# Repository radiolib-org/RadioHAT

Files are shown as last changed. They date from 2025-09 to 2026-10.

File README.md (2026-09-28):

# RadioHAT
Raspberry Pi PCIe HAT for radio modules

This HAT is an all-in-one radio modules development platform with the following features. 

* **Built-in logic analyzer** - All pins routed to the transceivers (SPI and various GPIO signals) are also routed to additional Raspberry Pi GPIO pins, to allow the RPi to monitor and record the state of communication pins. See the [pinalyzer repository](https://github.com/radiolib-org/pinalyzer) for details.
* **Adjustable linear voltage regulator** - To supply power-intensive transceivers, there is a dedicated LDO regulator with adjustable output. The output voltage is adjustable between 2.9 and 3.6 V.
* **Power consumption measurement** - There is a built-in INA219 current monitor which allows to measure the power consumption of the transceiver. See the [dc-powermon repository](https://github.com/radiolib-org/dc-powermon) for details.

While these features are useful, they are entirely optional. Without them, the HAT is a simple adapter board for mini-PCIe cards (half-size or full-size) and can be left with most of the components unpopulated, except for the RPi pin header, PCIe connector and the card latch.

## RadioHAT
RadioHAT

## Card for modules from Dorji
RadioHAT Dorji card

## Card for modules from GNice-RF
RadioHAT GNice-RF card

## Card for modules from Ebyte
RadioHAT Ebyte card

## Card for Wio-E5
RadioHAT Wio-E5 card

## Mini PCIe connector pinout
Different vendors (RAK Wireless, Waveshare, SeeedStudio and others) offer radio modules in the mini-PCIe card form factor. However, there seems to be no consensus on any specific pinout. Naturally, RadioLib defines its own version to add to the confusion. However, we try to adhere to the standard Mini PCIe 2.0 pinout in the following ways:

* Mini PCIe 2.0 SMB pins are used for I2C
* Mini PCIe 2.0 USB pins are used for USB
* IRQs, resets and various GPIOs are connected to Mini PCIe 2.0 digital signals
* 3.3V voltage pins are used for most modules, though sometimes 5V is optionally used 

The complete pinout of the connector (and therefore the PCIe cards) is shown below.

| Pin | Signal | Signal | Pin |
| --- | --- | --- | --- |
| 1 | GPIO0 | 3V3 | 2 |
| 3 | IRQ0 | GND | 4 |
| 5 | IRQ1 | 5V | 6 |
| 7 | GPIO1 | NC | 8 |
| 9 | GND | NC | 10  |
|  11 | RST0 | NC | 12  |
|  13 | RST1 | NC | 14  |
|  15 | GND | NC | 16  |
|  17 | NC | GND | 18  |
|  19 | NC | NSS1 | 20  |
|  21 | GND | NC | 22  |
|  23 | NC | 3V3 | 24  |
|  25 | NC | GND | 26  |
|  27 | GND | 5V | 28  |
|  29 | GND | I2C_SCL  | 30  |
|  31 | PPS | I2C_SDA  | 32  |
|  33 | NC | GND | 34  |
|  35 | GND | USB_D- | 36  |
|  37 | GND | USB_D+ | 38  |
|  39 | 3V3 | GND | 40  |
|  41 | 3V3 | LED0 | 42  |
|  43 | GND | LED1 | 44  |
|  45 | SPI_SCK  | LED2 | 46  |
|  47 | SPI_MISO | 5V | 48  |
|  49 | SPI_MOSI | GND | 50  |
|  51 | NSS0 | 3V3 | 52  |

## Raspberry Pi pinout

The shield routes the Mini PCIe connector signals to the following Raspberry Pi GPIO header pins. The pins with prefix `SNS_` are connected to the digital signals through a series resistor and GPIO, allowing to use the RPi as a makeshift logic analyzer.

| Pin | Signal | Signal | Pin |
| --- | --- | --- | --- |
| 1 | 3V3 | 5V | 2 |
| 3 | I2C_SCL | 5V | 4 |
| 5 | I2C_SDA | GND | 6 |
| 7 | SNS_NSS0  | SNS_SDA | 8 |
| 9 | GND | SNS_SCL | 10  |
|  11 | SNS_SCK | RST0 | 12  |
|  13 | SNS_MISO  | GND | 14  |
|  15 | SNS_MOSI  | GPIO1 | 16  |
|  17 | 3V3 | IRQ1 | 18  |
|  19 | SPI_MOSI  | GND | 20  |
|  21 | SPI_MISO  | RST1 | 22  |
|  23 | SPI_SCK | NSS0 | 24  |
|  25 | GND | NSS1 | 26  |
|  27 | NC | NC | 28  |
|  29 | SNS_IRQ0  | GND | 30  |
|  31 | SNS_RST0  | SNS_GPIO0 | 32  |
|  33 | SNS_NSS1  | GND | 34  |
|  35 | SNS_IRQ1  | IRQ0 | 36  |
|  37 | SNS_GPIO1 | GPIO0 | 38  |
|  39 | GND | SNS_RST1  | 40  |

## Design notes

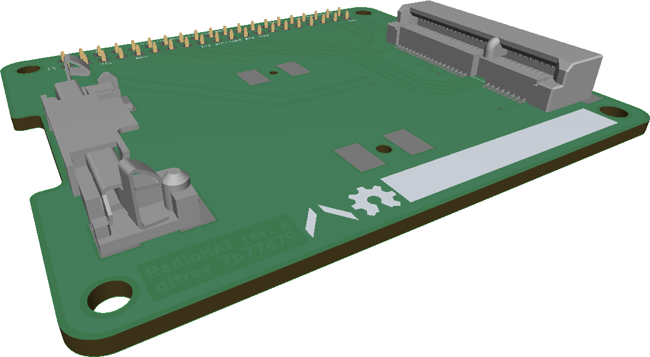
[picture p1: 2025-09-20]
doc/RadioHAT-3D_top.png

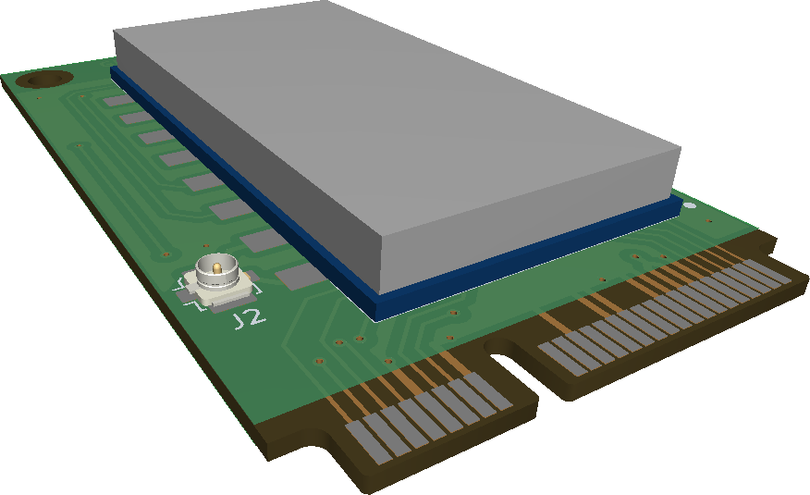
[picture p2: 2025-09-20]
doc/RadioHAT_Card_GNiceRF-3D_top.png

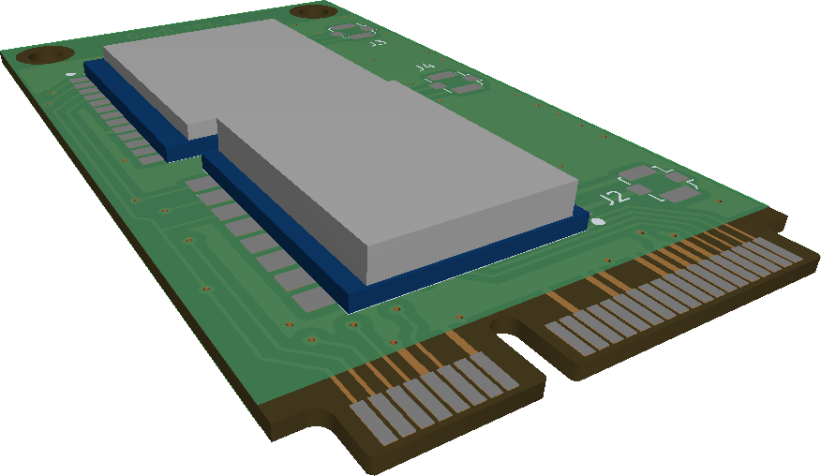
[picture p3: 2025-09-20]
doc/RadioHAT_Card_Dorji-3D_top.png

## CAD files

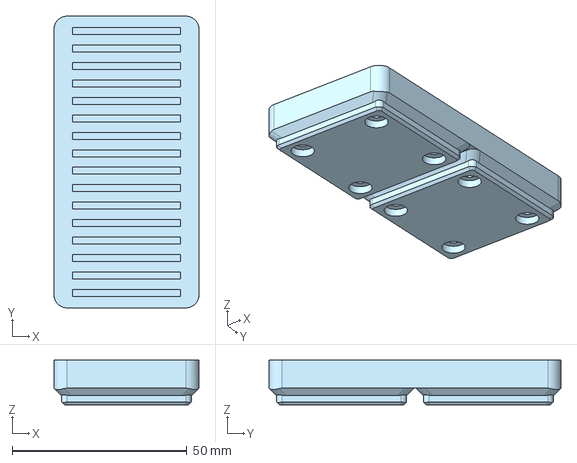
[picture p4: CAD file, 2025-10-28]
stp/gridfinity_card_holder.step
41.5 x 83.5 x 12.8 mm

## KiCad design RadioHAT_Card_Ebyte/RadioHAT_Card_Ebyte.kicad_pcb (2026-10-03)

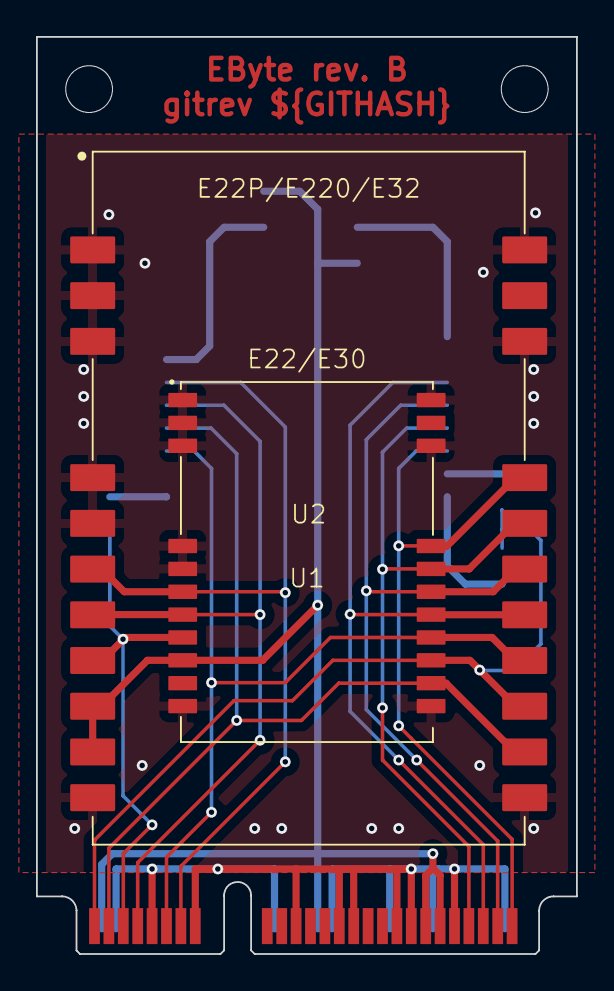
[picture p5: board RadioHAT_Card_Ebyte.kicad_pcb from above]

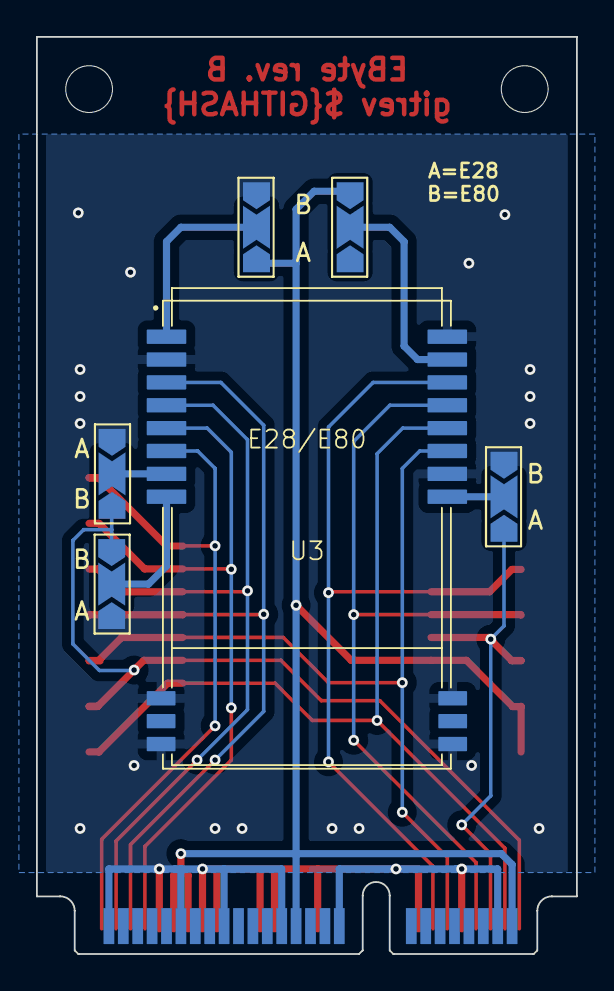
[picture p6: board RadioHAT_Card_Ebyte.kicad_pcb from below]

Board: 2 copper layers, 30.0 x 50.9 mm, 9 parts (6 on the bottom side), 17 nets.

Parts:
J1: Mini_PCIe_Full
JP1, JP2, JP3, JP4, JP5: SolderJumper_3_Open; SolderJumper-3_P2.0mm_Open_TrianglePad1.0x1.5mm_NumberLabels
U1: E22_Small
U2: E22_Large
U3: E28_E80

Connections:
+3V3: J1.2 (3V3), J1.24 (3V3), J1.39 (3V3), J1.41 (3V3), JP1.3 (B), JP2.1 (A), U1.9 (VCC), U2.9 (VCC), U2.10 (VCC)
GND: J1.4 (GND), J1.9 (GND), J1.15 (GND), J1.18 (GND), J1.21 (GND), J1.26 (GND), J1.27 (GND), J1.29 (GND), J1.34 (GND), J1.35 (GND), J1.37 (GND), J1.40 (GND), J1.43 (GND), J1.50 (GND), JP2.3 (B), JP3.3 (B), JP4.3 (B), JP5.1 (A), U1.1 (GND), U1.2 (GND), U1.3 (GND), U1.4 (GND), U1.5 (GND), U1.11 (GND), U1.12 (GND), U1.20 (GND_ANT), U1.22 (GND_ANT), U2.1 (GND), U2.2 (GND), U2.3 (GND), U2.4 (GND), U2.5 (GND), U2.11 (GND), U2.12 (GND), U2.20 (GND_ANT), U2.22 (GND_ANT), U3.2 (GND), U3.11 (GND_ANT), U3.13 (GND_ANT), U3.14 (GND_ANT), U3.16 (GND_ANT), U3.20 (GND), U3.26 (GND)
GPIO0: J1.1 (GPIO0), JP3.1 (A), JP5.3 (B), U1.14 (BUSY), U2.14 (BUSY)
GPIO1: J1.7 (GPIO1), U1.7 (TXEN), U2.7 (TXEN), U3.23 (DIO8/DIO1)
IRQ0: J1.3 (IRQ0), U1.13 (DIO1), U2.13 (DIO1), U3.22 (DIO9/BUSY)
IRQ1: J1.5 (IRQ1), JP4.1 (A), U1.8 (DIO2), U2.8 (DIO2)
MISO: J1.47 (SPI_MISO), U1.16 (MISO), U2.16 (MISO), U3.3 (MISO)
MOSI: J1.49 (SPI_MOSI), U1.17 (MOSI), U2.17 (MOSI), U3.4 (MOSI)
NSS: J1.51 (NSS0), U1.19 (NSS), U2.19 (NSS), U3.6 (NSS)
unnamed: JP1.2 (C), U3.25 (VCC/DIO3)
unnamed: JP2.2 (C), U3.1 (GND/VCC)
unnamed: JP3.2 (C), U3.8 (GND/RX_EN)
unnamed: JP4.2 (C), U3.19 (GND/TX_EN)
unnamed: JP5.2 (C), U3.7 (BUSY/GND)
RST0: J1.11 (RST0), U1.15 (NRST), U2.15 (NRST), U3.21 (NRST)
RST1: J1.13 (RST1), U1.6 (RXEN), U2.6 (RXEN), U3.24 (DIO7/DIO2)
SCK: J1.45 (SPI_SCK), U1.18 (SCK), U2.18 (SCK), U3.5 (SCK)

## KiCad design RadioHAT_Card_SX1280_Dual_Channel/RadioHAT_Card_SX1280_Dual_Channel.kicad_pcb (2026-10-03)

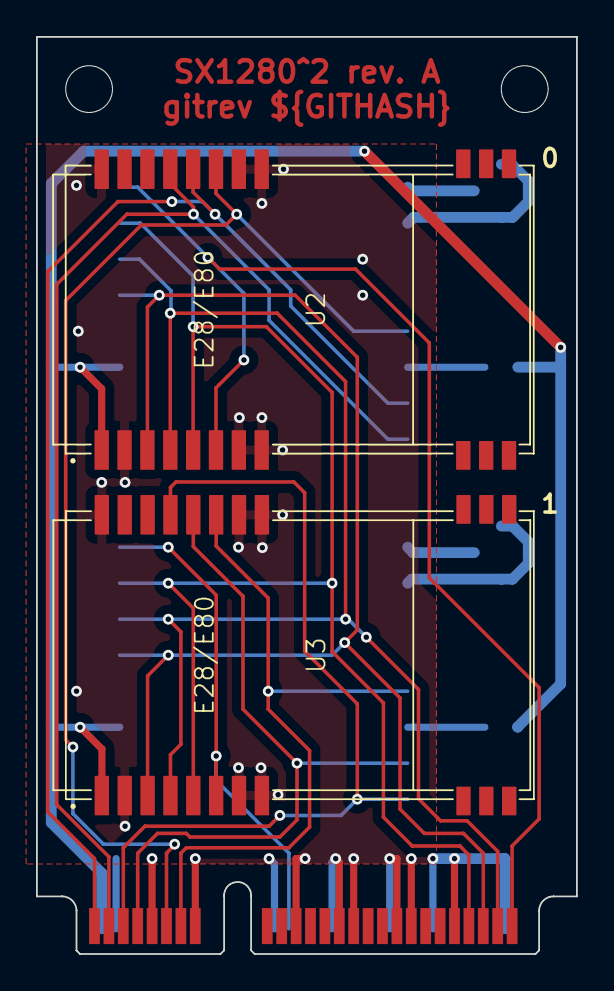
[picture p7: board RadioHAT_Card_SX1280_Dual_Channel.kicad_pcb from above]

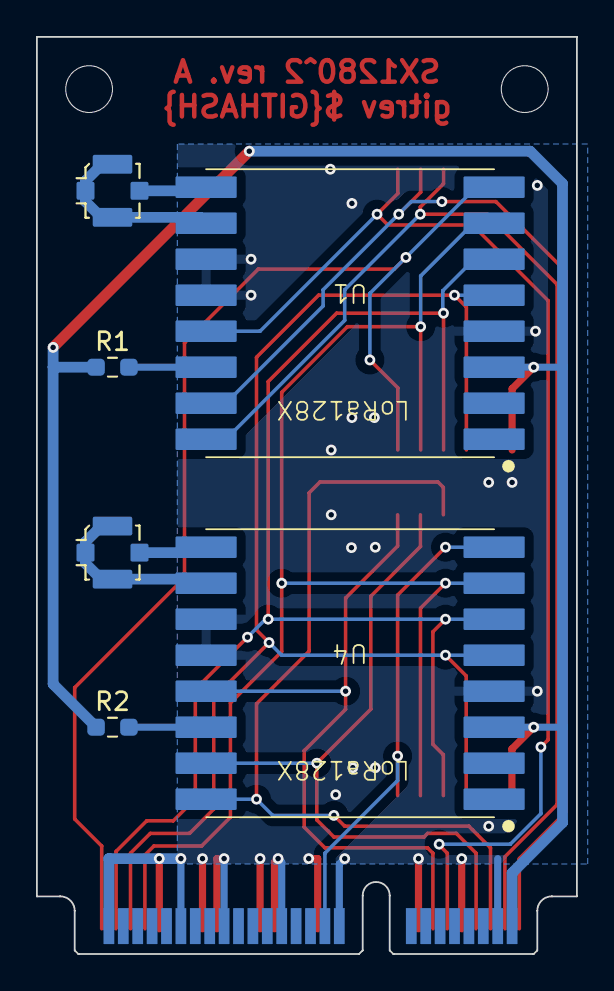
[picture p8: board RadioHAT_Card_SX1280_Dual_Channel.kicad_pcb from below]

Board: 2 copper layers, 30.0 x 51.0 mm, 9 parts (6 on the bottom side), 19 nets.

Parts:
J1: Mini_PCIe_Full
J2, J3: Conn_Coaxial; U.FL_Molex_MCRF_73412-0110_Vertical
R1, R2: 1k; R_0603_1608Metric_Pad0.98x0.95mm_HandSolder
U1, U4: LoRa128X
U2, U3: E28_E80

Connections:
+3V3: J1.2 (3V3), R1.1, R2.1, U1.3 (VCC), U2.1 (GND/VCC), U3.1 (GND/VCC), U4.3 (VCC)
GND: J1.4 (GND), J1.9 (GND), J1.15 (GND), J1.18 (GND), J1.21 (GND), J1.26 (GND), J1.27 (GND), J1.29 (GND), J1.34 (GND), J1.35 (GND), J1.37 (GND), J1.40 (GND), J1.43 (GND), J1.50 (GND), U1.4 (GND), U1.11 (GND), U1.12 (GND), U2.2 (GND), U2.7 (BUSY/GND), U2.8 (GND/RX_EN), U2.19 (GND/TX_EN), U2.20 (GND), U2.26 (GND), U3.2 (GND), U3.7 (BUSY/GND), U3.8 (GND/RX_EN), U3.19 (GND/TX_EN), U3.20 (GND), U3.26 (GND), U4.4 (GND), U4.11 (GND), U4.12 (GND)
GPIO0: J1.1 (GPIO0), U1.15 (BUSY), U2.22 (DIO9/BUSY)
GPIO1: J1.7 (GPIO1), U3.22 (DIO9/BUSY), U4.15 (BUSY)
IRQ0: J1.3 (IRQ0), U1.16 (DIO1), U2.23 (DIO8/DIO1)
IRQ1: J1.5 (IRQ1), U3.23 (DIO8/DIO1), U4.16 (DIO1)
MISO: J1.47 (SPI_MISO), U1.5 (MISO), U2.3 (MISO), U3.3 (MISO), U4.5 (MISO)
MOSI: J1.49 (SPI_MOSI), U1.6 (MOSI), U2.4 (MOSI), U3.4 (MOSI), U4.6 (MOSI)
NSS0: J1.51 (NSS0), U1.8 (NSS), U2.6 (NSS)
NSS1: J1.20 (NSS1), U3.6 (NSS), U4.8 (NSS)
unnamed: J2.2 (Ext), U1.10 (GND_ANT)
unnamed: J2.1 (In), U1.9 (ANT)
unnamed: J3.2 (Ext), U4.10 (GND_ANT)
unnamed: J3.1 (In), U4.9 (ANT)
unnamed: R1.2, U1.14 (TCXOEN)
unnamed: R2.2, U4.14 (TCXOEN)
RST0: J1.11 (RST0), U1.13 (NRESET), U2.21 (NRST)
RST1: J1.13 (RST1), U3.21 (NRST), U4.13 (NRESET)
SCK: J1.45 (SPI_SCK), U1.7 (SCK), U2.5 (SCK), U3.5 (SCK), U4.7 (SCK)

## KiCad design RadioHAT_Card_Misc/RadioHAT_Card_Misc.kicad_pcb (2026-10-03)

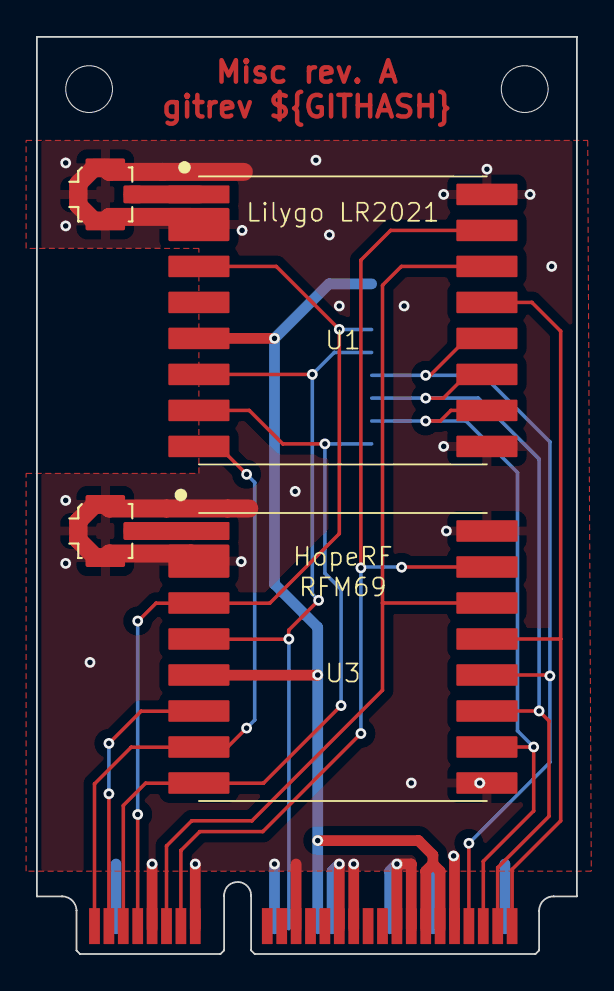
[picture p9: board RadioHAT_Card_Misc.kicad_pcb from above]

Board: 2 copper layers, 30.0 x 51.0 mm, 6 parts (1 on the bottom side), 15 nets.

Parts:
J1: Mini_PCIe_Full
J2, J3: Conn_Coaxial; U.FL_Molex_MCRF_73412-0110_Vertical
U1: Lilygo_LR2021
U2: nRF24
U3: RFM69

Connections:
+3V3: J1.24 (3V3), J1.39 (3V3), J1.41 (3V3), U1.5 (VCC), U2.1 (+3V3), U3.5 (VCC)
GND: J1.4 (GND), J1.9 (GND), J1.15 (GND), J1.18 (GND), J1.21 (GND), J1.26 (GND), J1.27 (GND), J1.29 (GND), J1.34 (GND), J1.35 (GND), J1.37 (GND), J1.40 (GND), J1.43 (GND), J1.50 (GND), J2.2 (Ext), J3.2 (Ext), U1.2 (GND_ANT), U1.9 (GND), U1.16 (GND), U2.2 (GND), U3.2 (GND), U3.9 (GND), U3.16 (GND)
GPIO0: J1.1 (GPIO0), U1.8 (BUSY), U3.7 (DIO1)
GPIO1: J1.7 (GPIO1), U1.3 (DIO8), U2.3 (CE), U3.3 (DIO3)
IRQ0: J1.3 (IRQ0), U3.6 (DIO0)
IRQ1: J1.5 (IRQ1), U1.7 (DIO11), U2.8 (IRQ), U3.8 (DIO2)
MISO: J1.47 (SPI_MISO), U1.10 (MISO), U2.7 (MISO), U3.10 (MISO)
MOSI: J1.49 (SPI_MOSI), U1.11 (MOSI), U2.6 (MOSI), U3.11 (MOSI)
NSS0: J1.51 (NSS0), U1.13 (NSS), U3.13 (NSS)
NSS1: J1.20 (NSS1), U1.6 (DIO10), U2.4 (CSN), U3.4 (DIO4)
unnamed: J2.1 (In), U1.1 (ANT)
unnamed: J3.1 (In), U3.1 (ANT)
RST0: J1.11 (RST0), U1.14 (NRESET), U3.14 (RST)
RST1: J1.13 (RST1), U1.15 (DIO9), U3.15 (DIO5)
SCK: J1.45 (SPI_SCK), U1.12 (SCK), U2.5 (SCK), U3.12 (SCK)

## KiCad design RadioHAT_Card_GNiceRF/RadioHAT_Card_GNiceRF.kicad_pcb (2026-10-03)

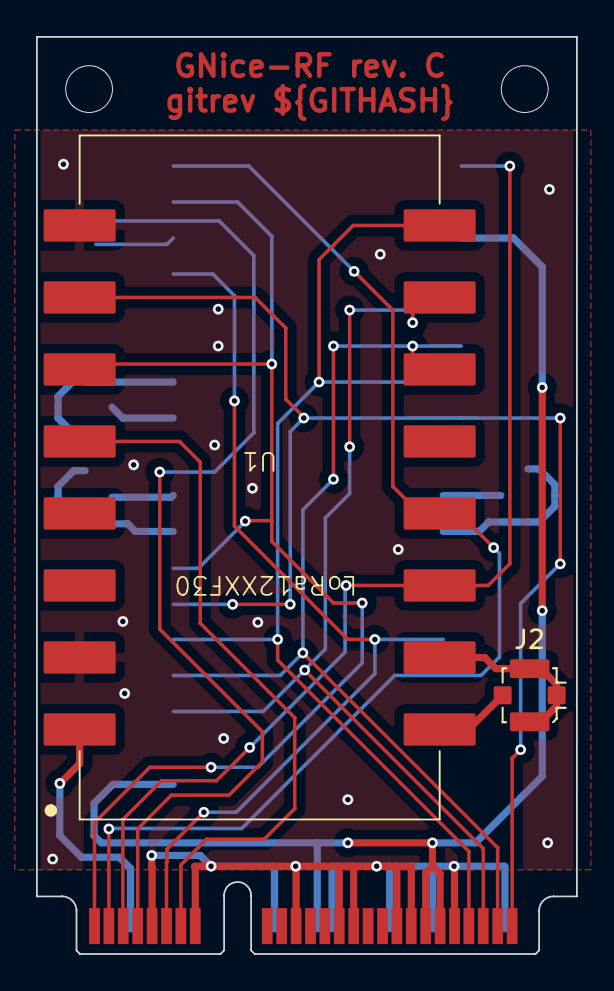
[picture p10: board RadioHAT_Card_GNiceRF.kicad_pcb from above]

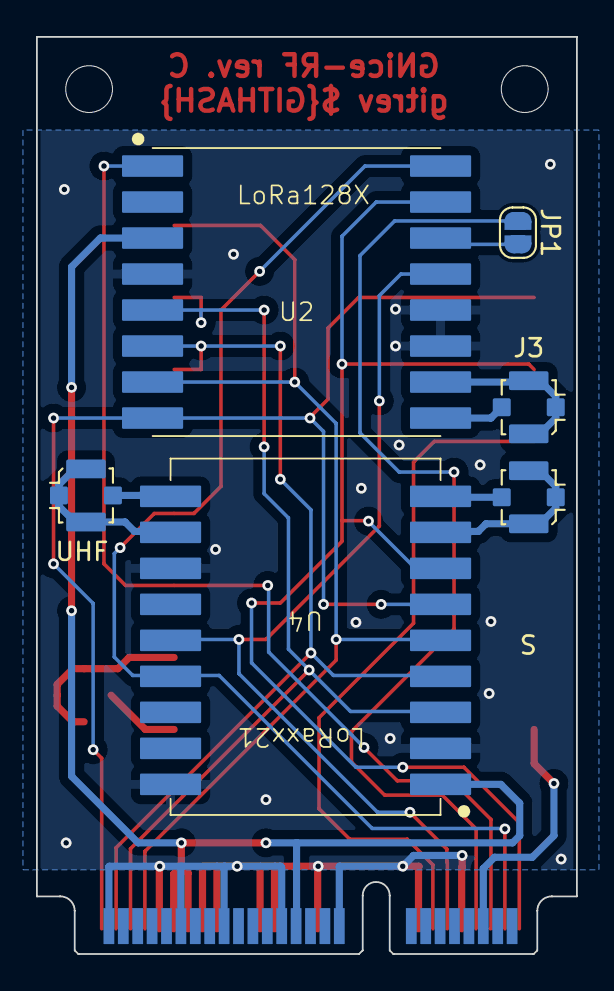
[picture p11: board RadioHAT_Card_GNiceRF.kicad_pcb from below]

Board: 2 copper layers, 30.0 x 51.0 mm, 9 parts (6 on the bottom side), 22 nets.

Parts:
J1: Mini_PCIe_Full
J2, J3, J4, J5: Conn_Coaxial; U.FL_Molex_MCRF_73412-0110_Vertical
JP1: SolderJumper_2_Open; SolderJumper-2_P1.3mm_Open_RoundedPad1.0x1.5mm
U1: LoRa12XXF30
U2: LoRa128X
U4: LoRaxx21

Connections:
+3V3: J1.24 (3V3), J1.39 (3V3), J1.41 (3V3), U2.3 (VCC), U4.1 (VCC)
+5V: J1.6 (5V), U1.1 (VCC)
GND: J1.9 (GND), J1.15 (GND), J1.18 (GND), J1.21 (GND), J1.26 (GND), J1.27 (GND), J1.29 (GND), J1.34 (GND), J1.35 (GND), J1.37 (GND), J1.40 (GND), J1.43 (GND), J1.50 (GND), U1.2 (GND), U1.8 (GND), U2.4 (GND), U2.11 (GND), U2.12 (GND), U4.2 (GND), U4.12 (GND), U4.18 (GND)
GPIO0: J1.1 (GPIO0), U1.6 (DIO0(BUSY)), U2.15 (BUSY), U4.7 (BUSY)
GPIO1: J1.7 (GPIO1), JP1.1 (A)
IRQ0: J1.3 (IRQ0), U1.13 (DIO1), U2.16 (DIO1), U4.15 (DIO9)
IRQ1: J1.5 (IRQ1), U1.14 (DIO4(DIO2)), U2.1 (DIO2)
MISO: J1.47 (SPI_MISO), U1.10 (MISO), U2.5 (MISO), U4.3 (MISO)
MOSI: J1.49 (SPI_MOSI), U1.11 (MOSI), U2.6 (MOSI), U4.4 (MOSI)
NSS: J1.51 (NSS0), U1.7 (NSS), U2.8 (NSS), U4.6 (NSS)
unnamed: J2.2 (Ext), U1.15 (GND_ANT)
unnamed: J2.1 (In), U1.16 (ANT)
unnamed: J3.2 (Ext), U2.10 (GND_ANT)
unnamed: J3.1 (In), U2.9 (ANT)
unnamed: J4.2 (Ext), U4.11 (GND_ANT)
unnamed: J4.1 (In), U4.10 (ANT)
unnamed: J5.2 (Ext), U4.8 (GND_ANT)
unnamed: J5.1 (In), U4.9 (2.4/S_ANT)
unnamed: JP1.2 (B), U2.14 (TCXOEN)
RST0: J1.11 (RST0), U2.13 (NRESET), U4.14 (RST)
RST1: J1.13 (RST1), U1.5 (NRESET)
SCK: J1.45 (SPI_SCK), U1.9 (SCK), U2.7 (SCK), U4.5 (SCK)

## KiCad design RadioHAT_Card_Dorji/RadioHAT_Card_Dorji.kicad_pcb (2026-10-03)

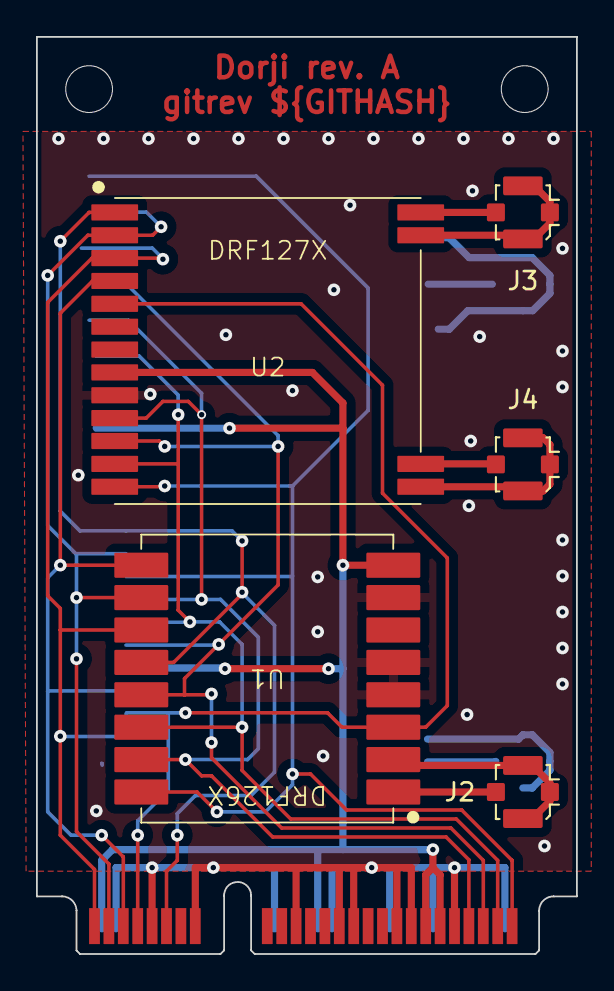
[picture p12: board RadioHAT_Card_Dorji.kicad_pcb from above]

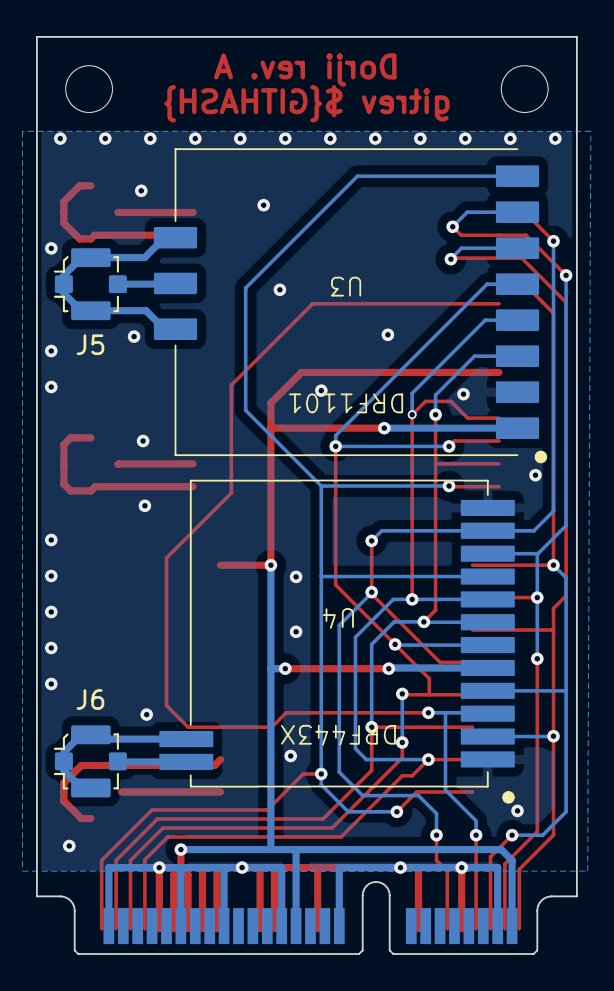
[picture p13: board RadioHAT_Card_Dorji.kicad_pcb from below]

Board: 2 copper layers, 30.0 x 51.0 mm, 10 parts (4 on the bottom side), 21 nets.

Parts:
J1: Mini_PCIe_Full
J2, J3, J4, J5, J6: Conn_Coaxial; U.FL_Molex_MCRF_73412-0110_Vertical
U1: DRF126X
U2: DRF127X
U3: DRF1101
U4: DRF443X

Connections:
+3V3: J1.2 (3V3), J1.24 (3V3), J1.39 (3V3), J1.41 (3V3), U1.8 (VDD), U2.8 (VCC), U3.1 (PWR), U4.5 (VCC)
GND: J1.4 (GND), J1.9 (GND), J1.15 (GND), J1.18 (GND), J1.21 (GND), J1.26 (GND), J1.27 (GND), J1.29 (GND), J1.34 (GND), J1.35 (GND), J1.37 (GND), J1.40 (GND), J1.43 (GND), J1.50 (GND), U1.4 (GND), U1.5 (GND), U1.7 (GND), U2.9 (GND), U3.2 (GND), U4.1 (GND), U4.12 (GND)
GPIO0: J1.1 (GPIO0), U1.11 (BUSY), U2.3 (DIO1), U3.6 (GPIO2), U4.2 (GPIO0)
GPIO1: J1.7 (GPIO1), U1.3 (SW), U2.5 (DIO3), U4.3 (GPIO1)
IRQ0: J1.3 (IRQ0), U1.10 (DIO1), U2.2 (DIO0), U3.7 (GPIO0), U4.10 (nIRQ)
IRQ1: J1.5 (IRQ1), U1.9 (DIO2), U2.4 (DIO2), U4.4 (GPIO2)
MISO: J1.47 (SPI_MISO), U1.13 (MISO), U2.11 (MISO), U3.5 (SDO), U4.6 (SDO)
MOSI: J1.49 (SPI_MOSI), U1.14 (MOSI), U2.12 (MOSI), U3.3 (SDI), U4.7 (SDI)
NSS: J1.51 (NSS0), U1.16 (NSS), U2.13 (NSS), U3.8 (CSN), U4.9 (nSEL)
unnamed: J2.2 (Ext), U1.2 (GND_ANT)
unnamed: J2.1 (In), U1.1 (ANT)
unnamed: J3.2 (Ext), U2.16 (GND_SX1278)
unnamed: J3.1 (In), U2.17 (ANT_SX1278)
unnamed: J4.2 (Ext), U2.14 (GND_SX1272)
unnamed: J4.1 (In), U2.15 (ANT_SX1272)
unnamed: J5.2 (Ext), U3.9 (GND_ANT), U3.11 (GND_ANT)
unnamed: J5.1 (In), U3.10 (ANT)
unnamed: J6.2 (Ext), U4.14 (GND_ANT)
unnamed: J6.1 (In), U4.13 (ANT)
RST0: J1.11 (RST0), U1.12 (RST), U2.1 (RESET), U4.11 (SDN)
SCK: J1.45 (SPI_SCK), U1.15 (SCK), U2.10 (SCK), U3.4 (SCLK), U4.8 (SCLK)

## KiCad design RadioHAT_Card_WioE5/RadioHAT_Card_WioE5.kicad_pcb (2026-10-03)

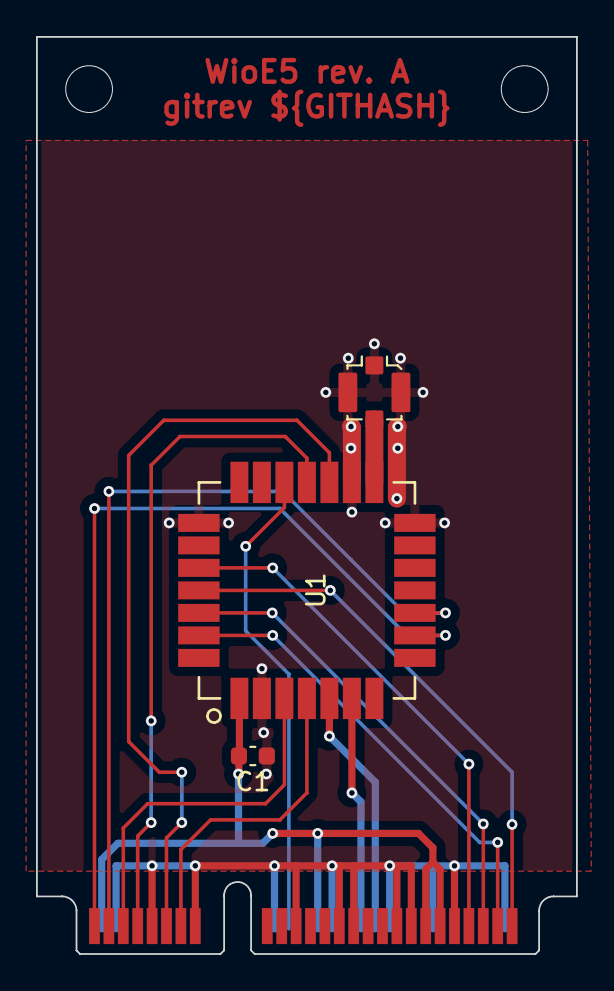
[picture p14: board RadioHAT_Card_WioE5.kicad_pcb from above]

Board: 2 copper layers, 30.0 x 51.0 mm, 4 parts (0 on the bottom side), 16 nets.

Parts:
C1: 100n; C_0603_1608Metric
J1: Mini_PCIe_Full
J2: Conn_Coaxial; U.FL_Molex_MCRF_73412-0110_Vertical
U1: LoRa-E5

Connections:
+3V3: C1.2, J1.2 (3V3), J1.24 (3V3), J1.39 (3V3), J1.41 (3V3), U1.1 (VCC)
GND: C1.1, J1.4 (GND), J1.9 (GND), J1.15 (GND), J1.18 (GND), J1.21 (GND), J1.26 (GND), J1.27 (GND), J1.29 (GND), J1.34 (GND), J1.35 (GND), J1.37 (GND), J1.40 (GND), J1.43 (GND), J1.50 (GND), J2.2 (Ext), U1.2 (GND), U1.14 (GND), U1.16 (GND), U1.22 (GND)
GPIO0: J1.1 (GPIO0), U1.9 (PB7)
GPIO1: J1.7 (GPIO1), U1.18 (PA3)
IRQ0: J1.3 (IRQ0), U1.10 (PB6)
IRQ1: J1.5 (IRQ1), U1.3 (PA13)
MISO: J1.47 (SPI_MISO), U1.26 (PB14)
MOSI: J1.49 (SPI_MOSI), U1.27 (PA10)
NSS0: J1.51 (NSS0), U1.25 (PB9)
NSS1: J1.20 (NSS1), U1.19 (PA2)
unnamed: J2.1 (In), U1.15 (RFIO)
RST0: J1.11 (RST0), U1.17 (RST)
RST1: J1.13 (RST1), U1.4 (PA14)
SCK: J1.45 (SPI_SCK), U1.24 (PB13~)
SCL: J1.32 (I2C_SCL), U1.5 (PB15)
SDA: J1.30 (I2C_SDA), U1.6 (PA15)

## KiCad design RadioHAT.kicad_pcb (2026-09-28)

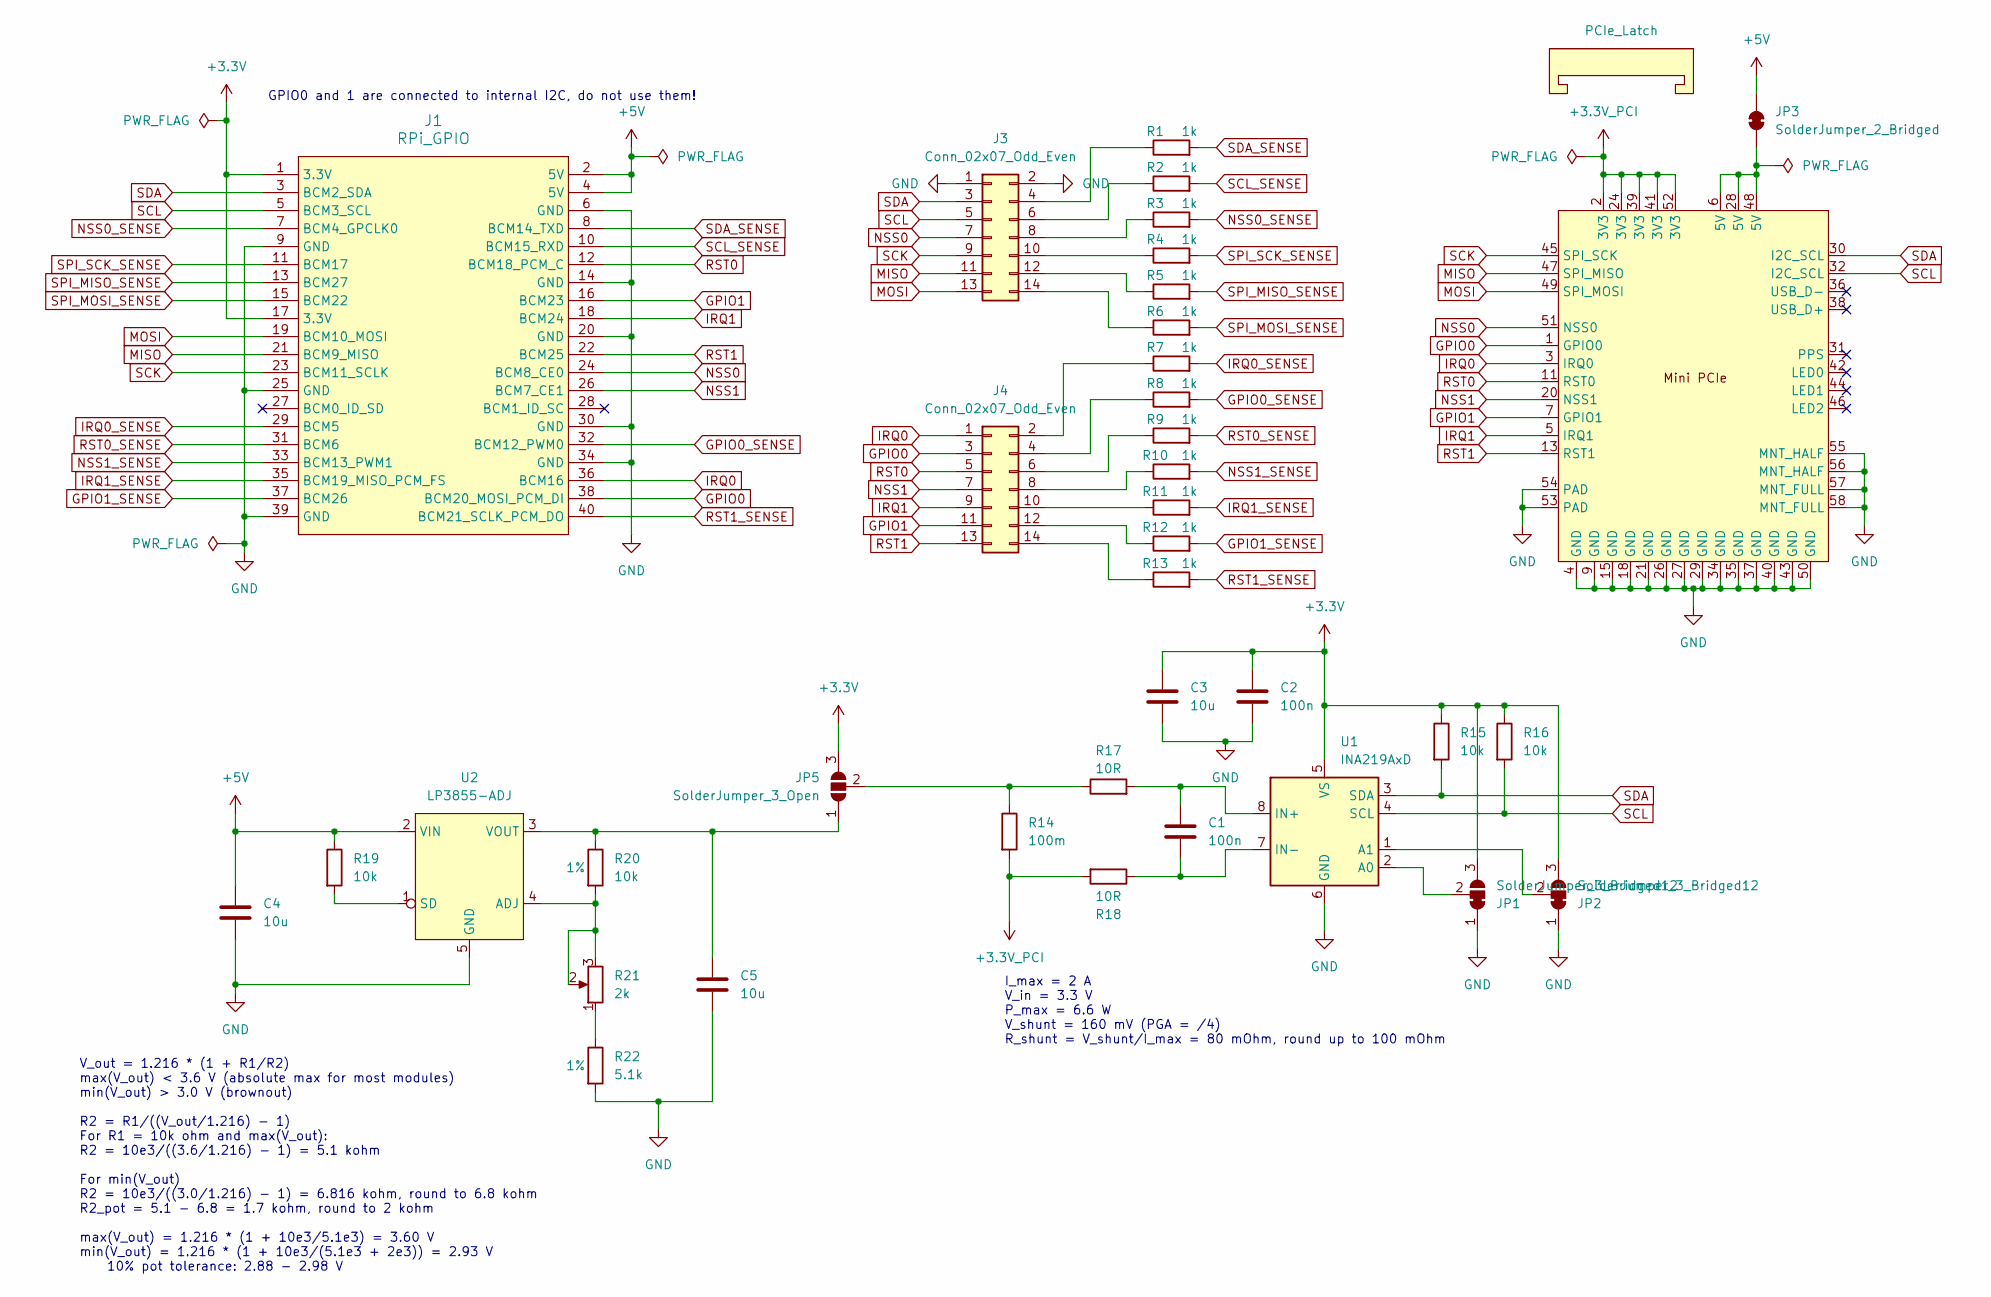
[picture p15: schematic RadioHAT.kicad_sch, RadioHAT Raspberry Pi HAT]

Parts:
C1, C2: 100n; C_0603_1608Metric_Pad1.08x0.95mm_HandSolder; Mouser 963-MAJCU168BB7104KT
C3, C4, C5: 10u; C_0805_2012Metric_Pad1.18x1.45mm_HandSolder; Mouser 581-KAM21AR71A106MU
J1: RPi_GPIO; RPI_Hat_B+; Mouser 200-SSQ12004TD
J2: Mini_PCIe_Latch_Hole; Mouser 571-1775838-2
J3, J4: Conn_02x07_Odd_Even; PinHeader_2x07_P2.54mm_Vertical; Mouser 523-G800LW589018EU
JP1, JP2: SolderJumper_3_Bridged12; SolderJumper-3_P1.3mm_Bridged12_Pad1.0x1.5mm_NumberLabels
JP3: SolderJumper_2_Bridged; SolderJumper-2_P1.3mm_Bridged_Pad1.0x1.5mm
JP5: SolderJumper_3_Open; SolderJumper-3_P1.3mm_Open_Pad1.0x1.5mm_NumberLabels
R1, R2, R3, R4, R5, R6, R7, R8, R9, R10, R11, R12, R13: 1k; R_0603_1608Metric_Pad0.98x0.95mm_HandSolder; Mouser 603-AC0603JR-131KL
R14: 100m; R_2512_6332Metric_Pad1.40x3.35mm_HandSolder_Bypass; Mouser 588-PCS2512DR1000ET
R15, R16, R19: 10k; R_0603_1608Metric_Pad0.98x0.95mm_HandSolder; Mouser 603-AF0603FR-0710KL
R17, R18: 10R; R_0603_1608Metric_Pad0.98x0.95mm_HandSolder; Mouser 71-CRCW060310R0FKEAC
R20: 10k; R_0603_1608Metric_Pad0.98x0.95mm_HandSolder; Tolerance 1%; Mouser 603-AF0603FR-0710KL
R21: 2k; Potentiometer_Bourns_3362P1200LF; Mouser 652-3362P-1-202LF
R22: 5.1k; R_0603_1608Metric_Pad0.98x0.95mm_HandSolder; Tolerance 1%; Mouser 279-CRG0603F5K1
U1: INA219AxD; SOIC-8_3.9x4.9mm_P1.27mm; Mouser 595-INA219AIDR
U2: LP3855-ADJ; SOT150P700X180-5N; Mouser 926-LP3855EMPADJNOPB
X1: PCIe_Latch; Mouser 538-48099-5701

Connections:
+3.3V: C2.1, C3.1, J1.1 (3.3V), J1.17 (3.3V), JP1.3 (B), JP2.3 (B), JP5.3 (B), R15.1, R16.1, U1.5 (VS)
+3.3V_PCI: J2.2 (3V3), J2.24 (3V3), J2.39 (3V3), J2.41 (3V3), J2.52 (3V3), R14.2, R18.2
+5V: C4.1, J1.2 (5V), J1.4 (5V), JP3.2 (B), R19.1, U2.2 (VIN)
GND: C2.2, C3.2, C4.2, C5.2, J1.6 (GND), J1.9 (GND), J1.14 (GND), J1.20 (GND), J1.25 (GND), J1.30 (GND), J1.34 (GND), J1.39 (GND), J2.4 (GND), J2.9 (GND), J2.15 (GND), J2.18 (GND), J2.21 (GND), J2.26 (GND), J2.27 (GND), J2.29 (GND), J2.34 (GND), J2.35 (GND), J2.37 (GND), J2.40 (GND), J2.43 (GND), J2.50 (GND), J2.53 (PAD), J2.54 (PAD), J2.55 (MNT_HALF), J2.56 (MNT_HALF), J2.57 (MNT_FULL), J2.58 (MNT_FULL), J3.1, J3.2, JP1.1 (A), JP2.1 (A), R22.2, U1.6 (GND), U2.5 (GND)
GPIO0: J1.38 (BCM20_MOSI_PCM_DI), J2.1 (GPIO0), J4.3
GPIO0_SENSE: J1.32 (BCM12_PWM0), R8.2
GPIO1: J1.16 (BCM23), J2.7 (GPIO1), J4.11
GPIO1_SENSE: J1.37 (BCM26), R12.2
IRQ0: J1.36 (BCM16), J2.3 (IRQ0), J4.1
IRQ0_SENSE: J1.29 (BCM5), R7.2
IRQ1: J1.18 (BCM24), J2.5 (IRQ1), J4.9
IRQ1_SENSE: J1.35 (BCM19_MISO_PCM_FS), R11.2
MISO: J1.21 (BCM9_MISO), J2.47 (SPI_MISO), J3.11
MOSI: J1.19 (BCM10_MOSI), J2.49 (SPI_MOSI), J3.13
NSS0: J1.24 (BCM8_CE0), J2.51 (NSS0), J3.7
NSS0_SENSE: J1.7 (BCM4_GPCLK0), R3.2
NSS1: J1.26 (BCM7_CE1), J2.20 (NSS1), J4.7
NSS1_SENSE: J1.33 (BCM13_PWM1), R10.2
unnamed: J3.4, R1.1
unnamed: J3.6, R2.1
unnamed: J3.8, R3.1
unnamed: J3.10, R4.1
unnamed: J3.12, R5.1
unnamed: J3.14, R6.1
unnamed: J4.2, R7.1
unnamed: J4.4, R8.1
unnamed: J4.6, R9.1
unnamed: J4.8, R10.1
unnamed: J4.10, R11.1
unnamed: J4.12, R12.1
unnamed: J4.14, R13.1
unnamed: JP1.2 (C), U1.2 (A0)
unnamed: JP2.2 (C), U1.1 (A1)
unnamed: J2.6 (5V), J2.28 (5V), J2.48 (5V), JP3.1 (A)
unnamed: C5.1, JP5.1 (A), R20.1, U2.3 (VOUT)
unnamed: JP5.2 (C), R14.1, R17.1
unnamed: R21.1, R22.1
unnamed: C1.1, R17.2, U1.8 (IN+)
unnamed: C1.2, R18.1, U1.7 (IN-)
unnamed: R20.2, R21.2, R21.3, U2.4 (ADJ)
unnamed: R19.2, U2.1 (SD)
RST0: J1.12 (BCM18_PCM_C), J2.11 (RST0), J4.5
RST0_SENSE: J1.31 (BCM6), R9.2
RST1: J1.22 (BCM25), J2.13 (RST1), J4.13
RST1_SENSE: J1.40 (BCM21_SCLK_PCM_DO), R13.2
SCK: J1.23 (BCM11_SCLK), J2.45 (SPI_SCK), J3.9
SCL: J1.5 (BCM3_SCL), J2.32 (I2C_SCL), J3.5, R16.2, U1.4 (SCL)
SCL_SENSE: J1.10 (BCM15_RXD), R2.2
SDA: J1.3 (BCM2_SDA), J2.30 (I2C_SCL), J3.3, R15.2, U1.3 (SDA)
SDA_SENSE: J1.8 (BCM14_TXD), R1.2
SPI_MISO_SENSE: J1.13 (BCM27), R5.2
SPI_MOSI_SENSE: J1.15 (BCM22), R6.2
SPI_SCK_SENSE: J1.11 (BCM17), R4.2

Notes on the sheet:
V_out = 1.216 * (1 + R1/R2) max(V_out) < 3.6 V (absolute max for most modules) min(V_out) > 3.0 V (brownout) R2 = R1/((V_out/1.216) - 1) For R1 = 10k ohm and max(V_out): R2 = 10e3/((3.6/1.216) - 1) = 5.1 kohm For min(V_out) R2 = 10e3/((3.0/1.216) - 1) = 6.816 kohm, round to 6.8 kohm R2_pot = 5.1 - 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
GPIO0 and 1 are connected to internal I2C, do not use them!
I_max = 2 A V_in = 3.3 V P_max = 6.6 W V_shunt = 160 mV (PGA = /4) R_shunt = V_shunt/I_max = 80 mOhm, round up to 100 mOhm

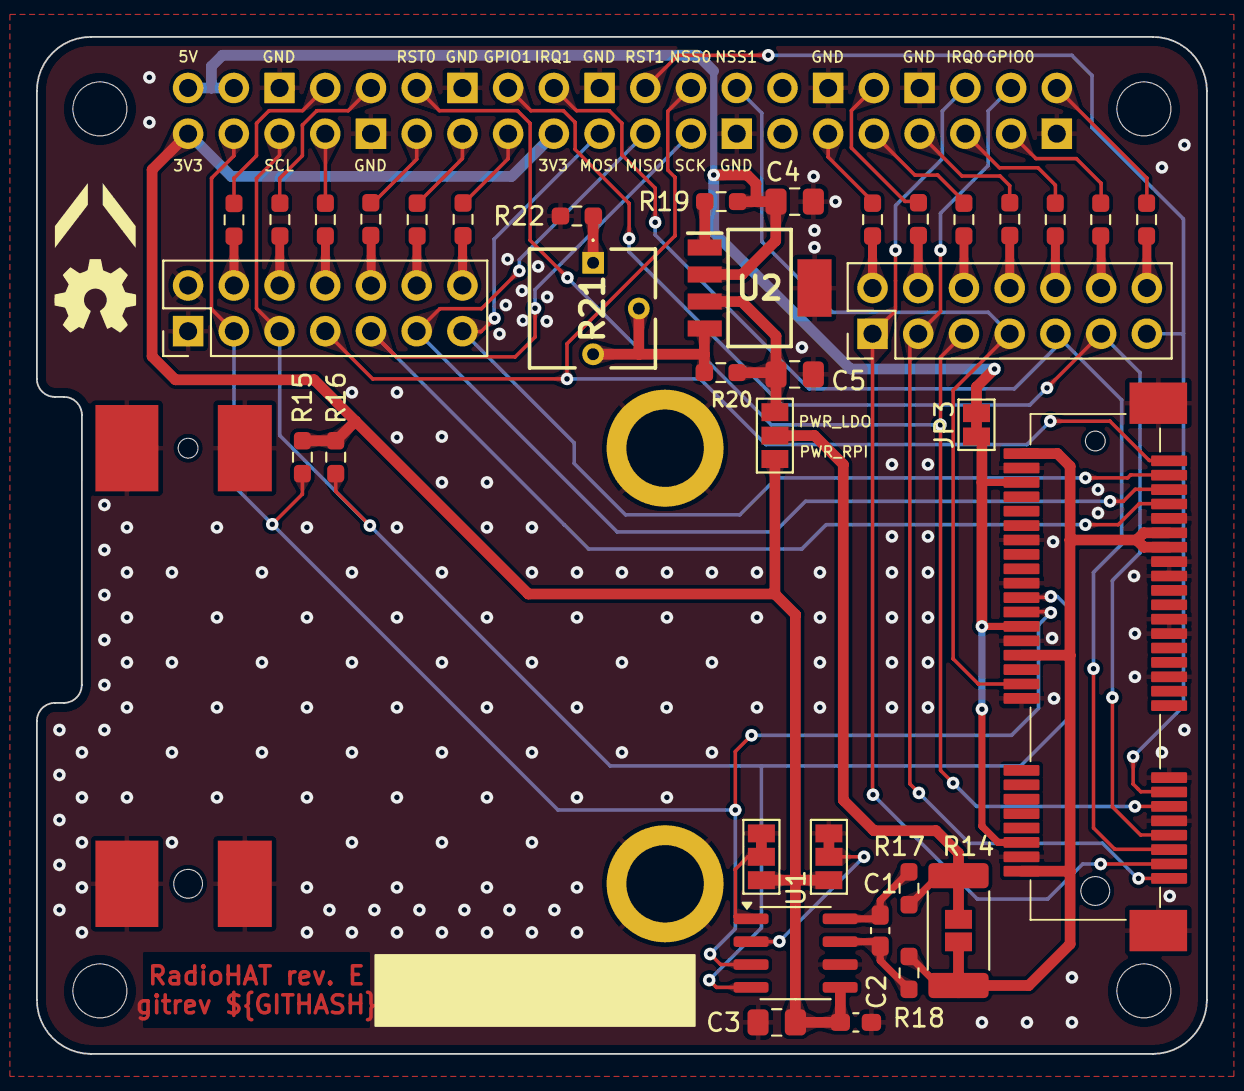
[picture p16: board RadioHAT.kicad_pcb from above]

Board: 2 copper layers, 65.0 x 56.5 mm, 37 parts (0 on the bottom side), 53 nets.

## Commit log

2025-08-11 Add gitignore for KiCAD projects
2025-08-11 Initial design
    [RadioHAT.kicad_pcb, RadioHAT.kicad_sch]
2025-08-16 PCIe card slot fix pins, add 3D model and TME link
2025-08-16 [SCH] Treat all ERC issues as errors and fix schematic
    [RadioHAT.kicad_sch]
2025-08-16 [PCB] Add 3D model to RPI board
    [RadioHAT.kicad_pcb]
2025-08-16 [PCB] Treat all DRC issues as errors and fix layout
    [RadioHAT.kicad_pcb]
2025-08-16 Add PCIe card footprints
    [RadioHAT.kicad_pcb]
2025-08-24 [PCB] Fix PCIe outline not closed
2025-08-24 [PCB] Remove soldermask from connector pins
2025-08-24 Add Dorji module symbols and footprints
2025-08-24 Add Dorji modules breakout card
    [RadioHAT_Card_Dorji.kicad_pcb, RadioHAT_Card_Dorji.kicad_sch]
2025-08-25 [PCB] Make card connector edges beveled
    [RadioHAT_Card_Dorji.kicad_pcb]
2025-08-28 Add 3D models to module footprints
2025-08-28 Change PCIe connector model and add standoff models
2025-08-28 [PCB] Update footprints
    [RadioHAT.kicad_pcb, RadioHAT_Card_Dorji.kicad_pcb]
2025-08-29 Add pinout to Pi GPIO header
    [RadioHAT.kicad_pcb]
2025-08-29 Add rev0 fab outputs
    [RadioHAT-B_Cu.gbr, RadioHAT-B_Mask.gbr, RadioHAT-B_Paste.gbr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]
2025-09-12 [PCB] Fix DRF443x pinout
2025-09-12 [PCB] Adjust radio position to move coax connector away from screw
    [RadioHAT_Card_Dorji.kicad_pcb]
2025-09-14 [PCB] Add keepout zones to card screw holes
2025-09-14 [PCB] Minor Dorji card fixes from rev0
    [RadioHAT_Card_Dorji.kicad_pcb, RadioHAT_Card_Dorji.kicad_sch]
2025-09-14 [PCB] Rotate card slot 180 deg, add description, gitrev and logos
    [RadioHAT.kicad_pcb]
2025-09-14 [PCB] Fix DRC warnings
    [RadioHAT.kicad_pcb]
2025-09-15 [PCB] Add mini PCIe variant with latch
2025-09-15 [PCB] Update HAT layout to use PCIe with latch
    [RadioHAT.kicad_pcb]
2025-09-15 [PCB] Rework modules to isolate antenna ground
    [RadioHAT_Card_Dorji.kicad_pcb, RadioHAT_Card_Dorji.kicad_sch]
2025-09-17 [PCB] Cleanup
    [RadioHAT.kicad_pcb]
2025-09-17 [PCB] Cleanup, move text
    [RadioHAT_Card_Dorji.kicad_pcb]
2025-09-17 Add GNiceRF Card
    [RadioHAT_Card_GNiceRF.kicad_pcb, RadioHAT_Card_GNiceRF.kicad_sch]
2025-09-17 Fix directory structure
    [RadioHAT_Card_GNiceRF.kicad_pcb, RadioHAT_Card_GNiceRF.kicad_sch]
2025-09-18 [PCB] Finalize labels
    [RadioHAT_Card_Dorji.kicad_pcb, RadioHAT_Card_GNiceRF.kicad_pcb]
2025-09-18 [CI] Fix KiCAD docker
2025-09-18 [PCB] Add git hash tag for CI
    [RadioHAT.kicad_pcb, RadioHAT_Card_Dorji.kicad_pcb, RadioHAT_Card_GNiceRF.kicad_pcb]
2025-09-18 [SCH] Update symbol from library
    [RadioHAT.kicad_sch]
2025-09-19 Fix ERC issues
    [RadioHAT_Card_Dorji.kicad_pcb, RadioHAT_Card_Dorji.kicad_sch]
2025-09-20 Fix library paths
    [RadioHAT_Card_Dorji.kicad_pcb]
2025-09-20 [PCB] Make githash variable
    [RadioHAT.kicad_pcb]
2025-09-20 [PCB] Make cards' githash variable
    [RadioHAT_Card_Dorji.kicad_pcb, RadioHAT_Card_GNiceRF.kicad_pcb]
2025-09-20 Remove fab data from repo (only in artifacts)
    [RadioHAT-B_Cu.gbr, RadioHAT-B_Mask.gbr, RadioHAT-B_Paste.gbr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]
2025-10-04 [PCB] Fix flipped pinout for 12XXF30
    [RadioHAT_Card_GNiceRF.kicad_pcb]
2025-10-04 [PCB] Fix minor DRC issue
    [RadioHAT_Card_GNiceRF.kicad_pcb]
2025-10-04 [PCB] Update latch footprint to make it easier to solder
    [RadioHAT.kicad_pcb]
2025-10-11 Add Ebyte card
    [RadioHAT_Card_Ebyte.kicad_pcb, RadioHAT_Card_Ebyte.kicad_sch]
2025-10-12 [PCB] Cleanup traces
    [RadioHAT_Card_Ebyte.kicad_pcb]
2025-10-12 [SCH] Fix power flags
    [RadioHAT_Card_Ebyte.kicad_sch]
2025-10-28 Add gridfinity card holder stepfile
    [gridfinity_card_holder.step]
2025-10-31 HAT rev C (GPIO sense, current measure, LDO)
    [RadioHAT.kicad_pcb, RadioHAT.kicad_sch]
2025-11-01 Move RPi HAT symbol and footprint to project library
2025-11-01 Update to use new RPi HAT
    [RadioHAT.kicad_pcb, RadioHAT.kicad_sch]
2025-11-01 Fix 4-way connection
    [RadioHAT.kicad_sch]
2025-11-01 [PCB] Cleanup to move all components to top side
    [RadioHAT.kicad_pcb]
2025-11-01 Rename footprint to match filter
    [RadioHAT.kicad_sch]
2025-11-01 Add 3D model for RPi connector
    [RadioHAT.kicad_pcb]
2025-11-02 [PCB] Add jumper texts
    [RadioHAT.kicad_pcb]
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2025-11-05 Implemented @RemyChatel recommendations
    [RadioHAT.kicad_pcb, RadioHAT.kicad_sch]
2025-11-09 [PCB] Use the same package for all 10u caps
    [RadioHAT.kicad_pcb]
2025-11-09 [SCH] Add Mouser part numbers
    [RadioHAT.kicad_sch]
2025-11-09 Add last remaining Mouser part numbers
    [RadioHAT.kicad_pcb, RadioHAT.kicad_sch]
2025-11-29 Fix LDO feedback resistors values and part numbers
    [RadioHAT.kicad_pcb, RadioHAT.kicad_sch]
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2025-12-05 [SCH] Move I2C address selection jumpers to 3V3 to simplify layout
    [RadioHAT.kicad_sch]
2025-12-05 [PCB] Move INA219 to not interfere with large modules
    [RadioHAT.kicad_pcb]
2025-12-07 Update G-NiceRF card to use LRxx21 instead of LR1120
    [RadioHAT_Card_GNiceRF.kicad_pcb, RadioHAT_Card_GNiceRF.kicad_sch]
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2025-12-16 Add KiCAD template for cards
    [RadioHAT_Card_Template.kicad_pcb, RadioHAT_Card_Template.kicad_sch]
2025-12-16 Fix errors in template
    [RadioHAT_Card_Template.kicad_pcb, RadioHAT_Card_Template.kicad_sch]
2025-12-16 Try to fix library symbol mismatch
    [RadioHAT_Card_Template.kicad_pcb, RadioHAT_Card_Template.kicad_sch]
2025-12-16 Update for new PCIe symbol
    [RadioHAT.kicad_pcb, RadioHAT.kicad_sch]
2025-12-16 Fix template card name not centered
    [RadioHAT.kicad_pcb, RadioHAT_Card_Template.kicad_pcb]
2025-12-19 Add courtyard to prevent collisions with bottom-mounted modules
2025-12-19 Fix possible collision with supply voltage solder bridge
    [RadioHAT.kicad_pcb]
2025-12-20 Add 5V power channel for PCI cards
    [RadioHAT.kicad_pcb, RadioHAT.kicad_sch]
2025-12-20 Fix missing power flag
    [RadioHAT.kicad_sch]
2025-12-21 Add 5V channel to GNiceRF card
    [RadioHAT_Card_GNiceRF.kicad_pcb, RadioHAT_Card_GNiceRF.kicad_sch]
2025-12-21 Add dual-channel SX1280 card
    [RadioHAT_Card_SX1280_Dual_Channel.kicad_pcb, RadioHAT_Card_SX1280_Dual_Channel.kicad_sch]
2025-12-22 Minor cleanup
    [RadioHAT_Card_SX1280_Dual_Channel.kicad_pcb]
2025-12-22 Update symbols to align with library
    [RadioHAT_Card_Dorji.kicad_pcb, RadioHAT_Card_Dorji.kicad_sch, RadioHAT_Card_Ebyte.kicad_pcb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]
2025-12-22 Fix pin conflict
    [RadioHAT_Card_SX1280_Dual_Channel.kicad_sch]
2025-12-22 Ignore solder mask bridge errors
2025-12-23 Fix paste on shunt resistor
    [RadioHAT.kicad_pcb]
2025-12-23 Ignore aperture bridges error
    [RadioHAT.kicad_pcb]
2025-12-23 Fix cards stackup
    [RadioHAT_Card_Dorji.kicad_pcb, RadioHAT_Card_Ebyte.kicad_pcb, RadioHAT_Card_SX1280_Dual_Channel.kicad_pcb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]
2026-01-10 Add part numbers
    [RadioHAT.kicad_sch]
2026-09-28 Set template board finish to HAL
    [RadioHAT_Card_Template.kicad_pcb]
2026-09-28 Minor HAT updates
    [RadioHAT.kicad_pcb, RadioHAT.kicad_sch]
2026-09-28 Add WioE5 card
    [RadioHAT_Card_WioE5.kicad_pcb, RadioHAT_Card_WioE5.kicad_sch]
2026-10-01 Add card for miscellaneous modules (nRF24, RF69, LR2021)
    [RadioHAT_Card_Misc.kicad_pcb, RadioHAT_Card_Misc.kicad_sch]
2026-10-03 Offset edge connector from board edge to simplify manufacturing
    [RadioHAT_Card_Dorji.kicad_pcb, RadioHAT_Card_Ebyte.kicad_pcb, RadioHAT_Card_GNiceRF.kicad_pcb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]
